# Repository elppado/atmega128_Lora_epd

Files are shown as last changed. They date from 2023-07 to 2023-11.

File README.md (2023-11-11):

# Atmega128_Lora_epd  wire-less Chat
## [ LoRa와 ePaper를 사용한 AVR 기반 저전력 다용도 통신 단말 ]

### 🚀 프로젝트 소개
------
atmega128과 Lora 모듈, 전자잉크 디스플레이를 사용하여 무선 채팅기 개발



### 🕰️ 개발 기간
------
* 22.07 ~ 22.09

### 📋 개발내용
------
- [Schematic](https://github.com/elppado/atmega128_Lora_epd/tree/main/PCB)
- [F/W](https://github.com/elppado/atmega128_Lora_epd/tree/main/firmware)  

### ⚙️ 개발환경
-----
* C
* **Tool** : xcode(avrdude_cross compile), kicad, fusion360

### 📋 BOM
------
Lora : NMT-UD434R0

Display : 2.13 inch EInk e-paper Display 250*122

Keypad : Q10

This project is licensed under the terms of the MIT license.

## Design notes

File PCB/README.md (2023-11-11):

# PCB
-------

- atmega128a
- LoRa Module
- e-ink display

### Schematic



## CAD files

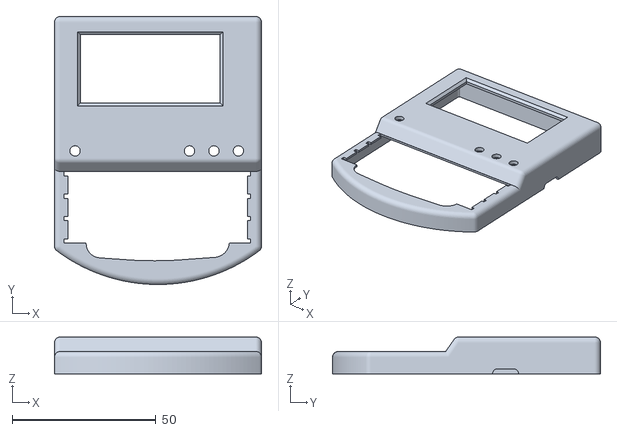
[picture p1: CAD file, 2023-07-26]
3D model/top.stl
72.0 x 93.2 x 12.9

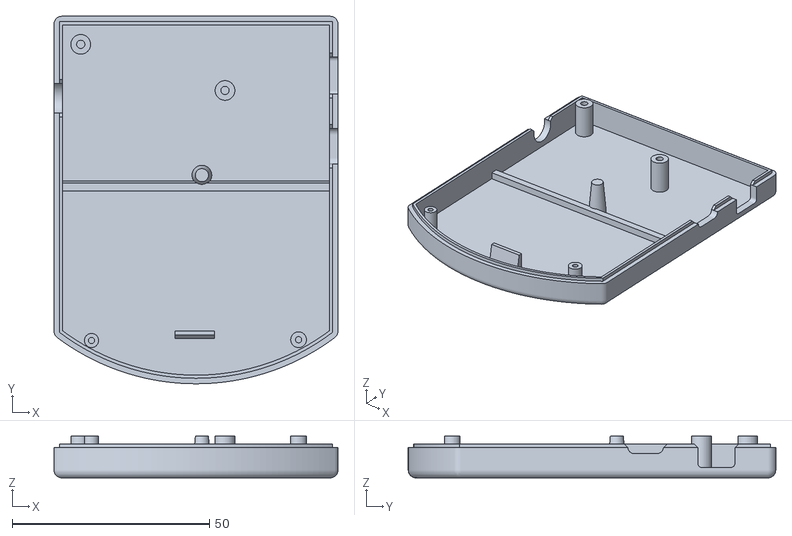
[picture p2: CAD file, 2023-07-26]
3D model/back.stl
72.0 x 93.2 x 10.6

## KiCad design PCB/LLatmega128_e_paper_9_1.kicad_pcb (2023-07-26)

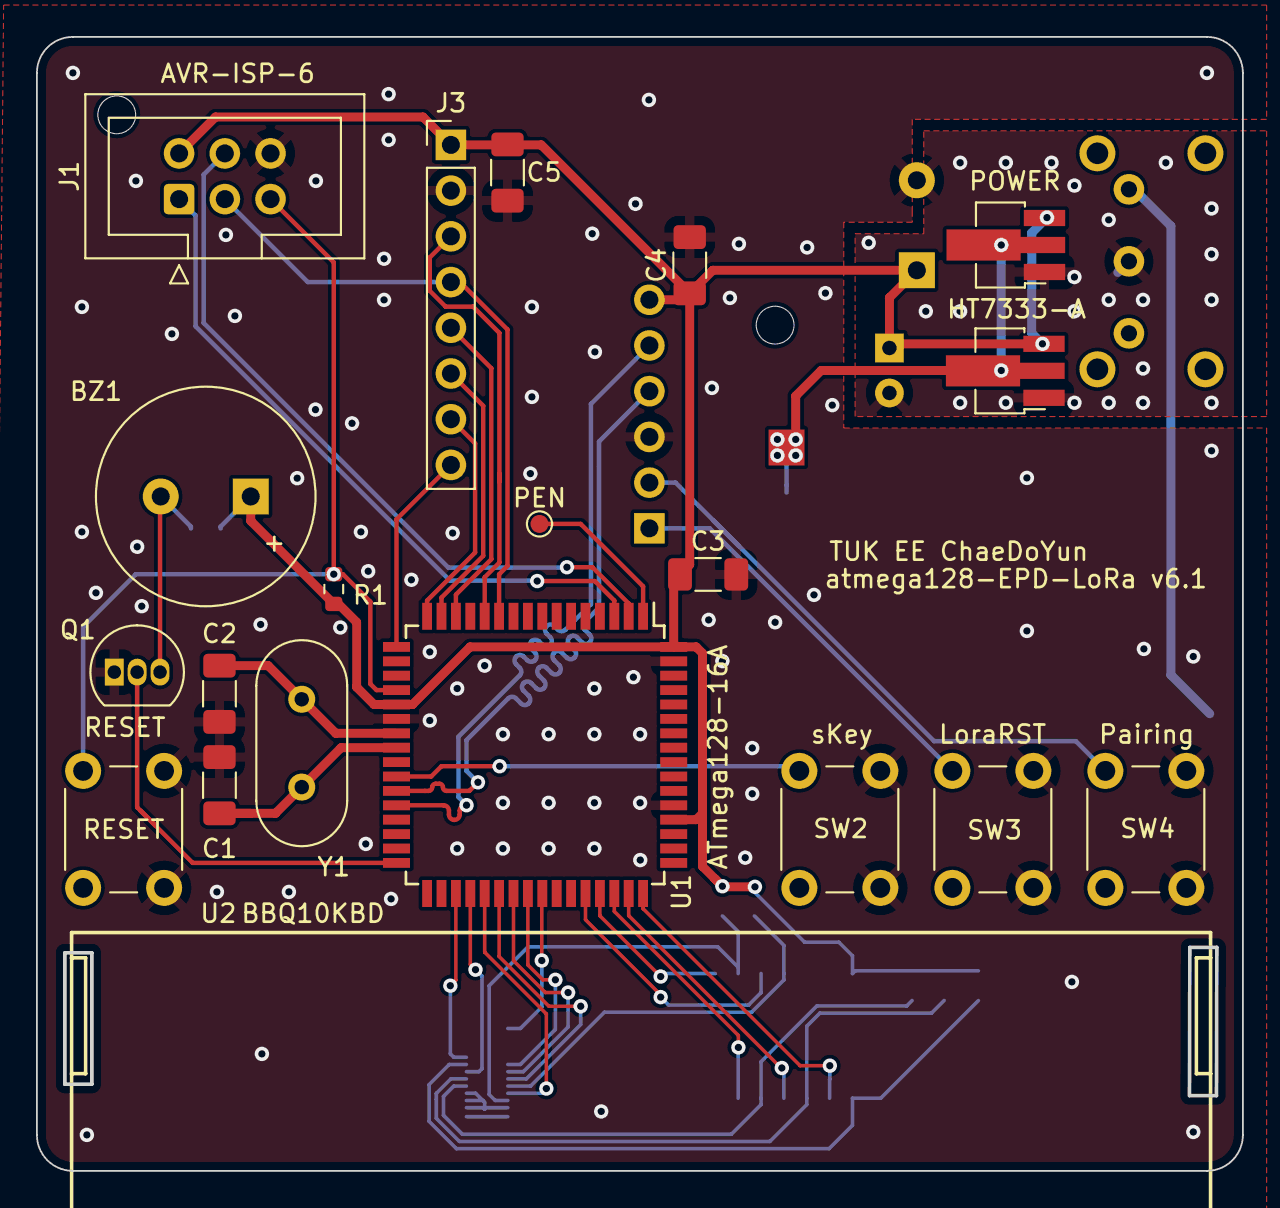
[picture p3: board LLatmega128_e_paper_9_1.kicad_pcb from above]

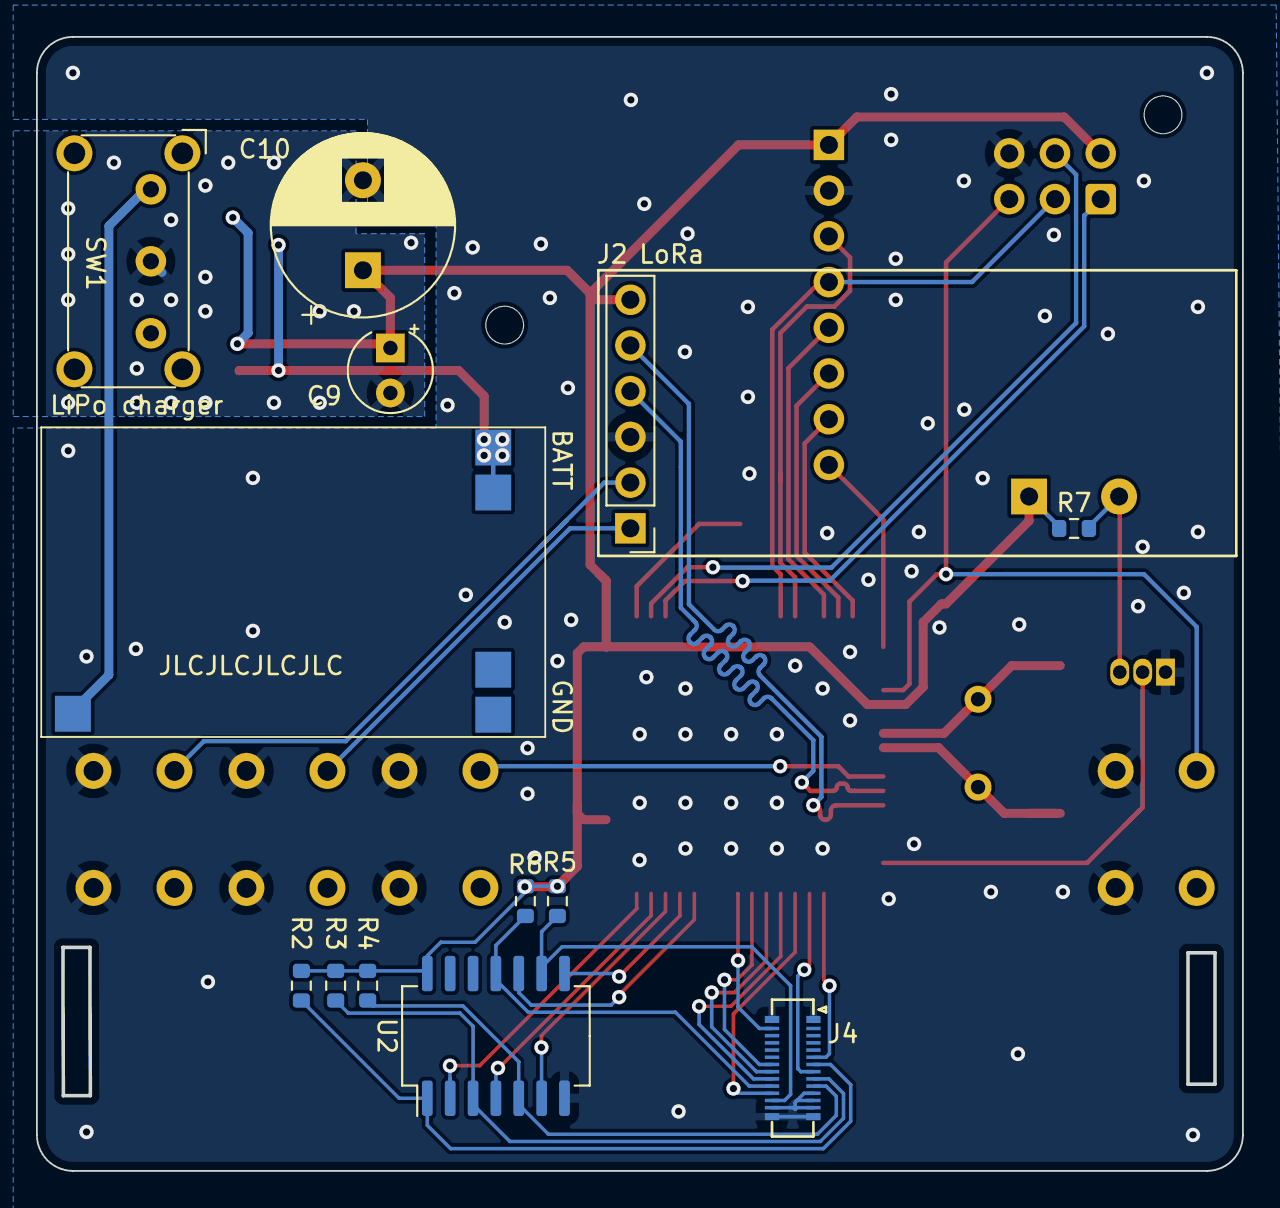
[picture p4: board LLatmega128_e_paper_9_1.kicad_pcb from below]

Board: 2 copper layers, 67.0 x 63.0 mm, 32 parts (12 on the bottom side), 38 nets.

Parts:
BZ1: Buzzer; Buzzer_12x9.5RM7.6
C1, C2: C22pF; C_1206_3216Metric_Pad1.33x1.80mm_HandSolder
C3, C4, C5: C_1206_3216Metric_Pad1.33x1.80mm_HandSolder
C9: CP_Radial_Tantal_D4.5mm_P2.50mm
C10: CP_Radial_D10.0mm_P5.00mm
J1: AVR-ISP-6; IDC-Header_2x03_P2.54mm_Vertical
J2: Conn_01x06_Male; PinHeader_1x06_P2.54mm_Vertical
J3: ePaper; PinHeader_1x08_P2.54mm_Vertical
J4: Conn_02x14_Counter_Clockwise; Hirose_BM14-24DS-2DSA_2x14_P2.00mm_Vertical
L1, L1#2: HT7333-A; SOT-89-3_Handsoldering
PEN: TestPoint_Pad_D1.0mm
POWER: SW_E-Switch_EG1224_SPDT_Angled
Q1: PN2222A; TO-92_Inline
R1: R10k; R_0603_1608Metric
R2, R3, R4, R5, R6, R7: R; R_0603_1608Metric
SW1, SW2, SW3, SW4: SW_Push; SW_PUSH_6mm_H4.3mm
U1: ATmega128-16A; TQFP-64_14x14mm_P0.8mm
U2: BBQ10KBD; Reverb_BTDR-1A
U2#2: 74HC14; SO-14_5.3x10.2mm_P1.27mm
Y1: Crystal; Crystal_HC49-4H_Vertical

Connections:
+3V3: BZ1.1 (-), C3.1, C4.1, C5.1, C9.1, C10.1, J1.2 (VCC), J2.6, J3.1, L1.3 (VOUT), L1#2.3 (VOUT), R1.1, R2.1, R3.1, R4.1, R5.1, R6.1, R7.1, U1.21 (VCC), U1.52 (VCC), U1.64 (AVCC), U2#2.14 (VCC)
-BATT: L1.2 (VIN), L1#2.2 (VIN)
/BUSY: J3.8, U1.17 (PB7)
/BUZZ: Q1.2 (B), U1.32 (PD7)
/COL1: U1.48 (PA3), U2#2.2
/COL2: U1.47 (PA4), U2#2.4
/COL3: U1.46 (PA5), U2#2.6
/COL4: U1.45 (PA6), U2#2.8
/COL5: U1.44 (PA7), U2#2.10
/CS: J3.5, U1.14 (PB4)
/D/C: J3.6, U1.15 (PB5)
/KCOL1: J4.7, R2.2, U2#2.1
/KCOL2: J4.9, R3.2, U2#2.3
/KCOL3: J4.10, R4.2, U2#2.5
/KCOL4: J4.17, R5.2, U2#2.9
/KCOL5: J4.19, R6.2, U2#2.11
/LoraRST: J2.1, SW3.2
/PIO6: J2.2, SW4.2
/RES: J3.7, U1.16 (PB6)
/ROW1: J4.6, U1.35 (PC0)
/ROW2: J4.8, U1.36 (PC1)
/ROW3: J4.18, U1.37 (PC2)
/ROW4: J4.20, U1.38 (PC3)
/ROW5: J4.21, U1.39 (PC4)
/ROW6: J4.22, U1.40 (PC5)
/ROW7: J4.27, U1.41 (PC6)
/RST: J1.5 (~RST), R1.2, SW1.2, U1.20 (~RESET)
/RXD0: J1.4 (MOSI), U1.2 (PE0)
/RXD1: J2.4, U1.27 (PD2)
/SCK: J1.3 (SCK), J3.4, U1.11 (PB1)
/SDI: J3.3, U1.12 (PB2)
/TXD0: J1.1 (MISO), U1.3 (PE1)
/TXD1: J2.5, U1.28 (PD3)
/X1: C1.2, U1.24 (XTAL1), Y1.2
/X2: C2.1, U1.23 (XTAL2), Y1.1
/sKEY: SW2.2, U1.26 (PD1)
GND: C1.1, C2.2, C3.2, C4.2, C5.2, C9.2, C10.2, J1.6 (GND), J2.3, J3.2, J4.1, J4.4, J4.5, J4.11, J4.12, J4.13, J4.14, J4.15, J4.16, J4.28, L1.1 (GND), L1#2.1 (GND), POWER.2, Q1.1 (E), SW1.1, SW2.1, SW3.1, SW4.1, U1.22 (GND), U1.53 (GND), U1.63 (GND), U2#2.7 (GND)
unnamed: BZ1.2 (+), Q1.3 (C), R7.2

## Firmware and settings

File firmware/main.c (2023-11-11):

/*
 * ATMEGAEPDLORA v1.c
 *
 * Created: 2022-07-17 오후 1:12:52
 * Author : chaedoyun
 */


//#define dev_colour_BLACK
#define dev_colour_WHITE


#include <avr/io.h>
#include <util/delay.h>
#include <avr/interrupt.h>
#include <avr/pgmspace.h>

#include "epd.h"
#include "buzz.h"
#include "keyscan.h"
#include "GPS.h"
//#include "uart.h"

#ifdef dev_colour_WHITE
    #include "font_W.h"

#else
    #include "font_B.h"
#endif


#define MAX_LEN 23



unsigned char TX_str[MAX_LEN];
unsigned char RX_str[MAX_LEN];
const unsigned char erase_str[MAX_LEN] = " ";

const unsigned char GPS_comm[] = "$gps";
const unsigned char GPS_dis_comm[]= "$dis";
const unsigned char Time_comm[] = "$time";


unsigned char str_po = 0;
unsigned char RX_po = 0;

unsigned char flag = 0;
unsigned char rx_flag = 1;




void str_to_epd(const unsigned char *str,unsigned char x, unsigned char y){ //str을 화면에 출력
    
    for (unsigned char i = 0; *(str+i) != '\0'; i++) {
        EPD_HW_Init(); // deepsleep 이후에 HW reset으로 꺠우기
        EPD_Dis_Part(x,y+(i*9),epd_font[(*(str+i)-32)],8,16);
        EPD_DeepSleep();
    }
}


void rx_str_sum(unsigned char *str, const unsigned char val){   //rx data 저장
    for (int i = 0; i < MAX_LEN; i++){
        if (*(str+i) == '\0'){
            *(str+i) = val;
            *(str+i+1) = '\0';
            
            return;
        }
    }
}

void str_sum(unsigned char *str, const unsigned char val){  // 키보드 입력 문자 덧셈
    *(str+flag) = val;
    *(str+flag+1) = '\0';
    flag++;
}


void init_UART1(unsigned char baud){    // uart1 init
    UBRR1H = (unsigned char)(baud >> 8);
    UBRR1L = (unsigned char)baud;
    
    UCSR1A &= ~(1 << U2X1);
    UCSR1B |= (1 << TXEN1) | (1 << RXEN1) | ( 1 << RXCIE1);
    UCSR1B &= ~(1 << UCSZ12);
    UCSR1C &= ~( 1 << UMSEL1) & ~( 1 << UPM11) & ~( 1 << UPM10) & ~( 1 << USBS1);
    UCSR1C |= (1<<UCSZ11) | (1 << UCSZ10);
}


void word_UART1(const unsigned char data){  // uart rx word 가져오기
    while( !(UCSR1A & (1<<UDRE1)));
    UDR1 = data;
}


void str_UART1(const unsigned char *str){   // uart rx str 가져오기
    while (*str != '\0') {
        word_UART1(*str);
        str++;
    }
    word_UART1(CR);
    word_UART1(LF);
}



void comm_find(void){
    switch (RX_str[0]) {
        case DC1:   // case GPS
            GPS_return();
            break;
            
        case DC2:   // case Lati
            for (unsigned char i = 0; RX_str[i] != 0; i++)
                you_GPS_lati[i] = RX_str[i+1];
            GPS_return_logi_flag = 0;
            break;
            
        case DC3:   // case logi
            for (unsigned char i = 0; RX_str[i] != 0; i++)
                you_GPS_logi[i] = RX_str[i+1];
            GPS_return_lati_flag = 0;
            break;
            
        default:    // 일반 메세지 처리
            SSound(Do);
            SSound(Re);
            str_to_epd(RX_str,RX_x,RX_y);
            break;
    }
    for (unsigned char i = 0; i < MAX_LEN; i++)
        RX_str[i] = '\0';
}



/* 수신 > 문자열 저장
 문자열 시작이 DC1|DC2|DC3 > GPS처리
 아니면 일반문자열로 처리 (화면 출력)
 */


ISR(USART1_RX_vect){ //  UART RX 인터럽트
    unsigned char ch = UDR1;
    if ((ch != CR) && (ch != LF)) {
        rx_str_sum(RX_str,ch);
    }
    else if (ch == LF){
        comm_find();
    }
}


void init_port(){
    DDRA = 0xff;
    DDRD |= (1 << PD7);
    DDRD &= ~(1 << PD1);
    PORTD |= (1 << PD1);
    DDRB = 0x7f;
    DDRC = 0x00;
}


void init_BOOT(){
    interrupt_init();
    init_port();
    PORTC = 0xff;
    init_UART1(47); // baud rate 47, 9600bps, fosc = 7.3728 MHz
    init_UART0(47);
    
    SSound(Do);
    
    EPD_HW_Init();
    EPD_SetRAMValue_BaseMap(gImage_1);
    EPD_DeepSleep();

    SSound(Mi);
    SSound(Sol);
    // 부팅 완료;
}


int main(void){
    unsigned char kval = '\0';
    
    init_BOOT();
    
    while (1) {
        if (keyScan()) {
            
            kval = kbdq10[alt_flag][keypad_in()];
            
            if (kval != '\0'){ // 리턴값이 \0 (사용하지 않는 키패드) 이면서
                EPD_HW_Init();
                
                switch (kval) {
                    case CR:
                        if (TX_str[0] == '$') {    // 특수 호출 메세지 시작값
                            
                            if ((TX_str[1] == GPS_comm[1]) && (TX_str[2] == GPS_comm[2]) && (TX_str[3] == GPS_comm[3]))  {
                                EPD_SetRAMValue_BaseMap(gImage_1);
                                EPD_DeepSleep();
                                GPS();
                            }
                            else if ((TX_str[1] == GPS_dis_comm[1]) && (TX_str[2] == GPS_dis_comm[2]) && (TX_str[3] == GPS_dis_comm[3])){
                                EPD_SetRAMValue_BaseMap(gImage_1);
                                EPD_DeepSleep();
                                GPS_dis();
                            }
                            else if ((TX_str[1] == Time_comm[1]) && (TX_str[2] == Time_comm[2]) && (TX_str[3] == Time_comm[3]) && (TX_str[4] == Time_comm[4])){
                                EPD_SetRAMValue_BaseMap(gImage_1);
                                EPD_DeepSleep();
                                get_time();
                            }
                        }
                        
                        else{
                            //word_UART1(DC4);
                            str_UART1(TX_str); //UART 송신
                            SSound(Re);//송신 완료 알림
                            SSound(Do);
                            
                            _delay_ms(3000);
                            EPD_SetRAMValue_BaseMap(gImage_1);
                            EPD_DeepSleep();
                        }
                        
                        for (unsigned char i = 0; i < MAX_LEN; i++){
                            TX_str[i] = '\0'; // TX, 디스플레이 후 문자열 버퍼 초기화
                        }
                        str_po = 0;
                        flag = 0;
                        break;
                    
                    case BS:
                        str_po--; //커서--
                        
                        if (str_po < 0)
                            str_po = 0;
                        
                        flag--; //문자열 합치기--
                        
                        if (flag < 0)
                            flag = 0;
                        
                        EPD_HW_Init();
                        EPD_Dis_Part(TX_x,TX_y+(str_po*9),epd_font[0],8,16);
                        EPD_DeepSleep();
                        break;
                        
                    case SPB:
                        str_sum(TX_str,kval); // 문자열 뒤에 추가.
                        str_po++;// 커서 위치
                        break;
                        
                    default:
                        str_sum(TX_str,kval); // 문자열 뒤에 추가.
                        EPD_Dis_Part(TX_x,TX_y+(str_po*9),epd_font[(kval-32)],8,16); // 키보드 입력한 한글자만 화면 출력
                        //word_UART1(kval);
                        EPD_DeepSleep();
                        str_po++; // 커서 위치
                        break;
                }
            }
        }
    }
}

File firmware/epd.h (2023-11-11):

/*
 * epd.h
 *
 * Created: 2022-07-17 오후 1:14:07
 *  Author: chaedoyun
 */ 


#ifndef EPD_H_
#define EPD_H_


#define SCK_Pin PB1
#define SDI_Pin PB2
#define CS_Pin PB4
#define DC_Pin PB5
#define RES_Pin PB6
#define BUSY PB7


#define EPD_W21_MOSI_0	PORTB &= ~( 1<< SDI_Pin)
#define EPD_W21_MOSI_1	PORTB |= ( 1<< SDI_Pin)

#define EPD_W21_CLK_0	PORTB &= ~( 1<< SCK_Pin)
#define EPD_W21_CLK_1	PORTB |= ( 1<< SCK_Pin)

#define EPD_W21_CS_0	PORTB &= ~( 1<< CS_Pin)
#define EPD_W21_CS_1	PORTB |= ( 1<< CS_Pin)

#define EPD_W21_DC_0	PORTB &= ~( 1<< DC_Pin)
#define EPD_W21_DC_1	PORTB |= ( 1<< DC_Pin)

#define EPD_W21_RST_0	PORTB &= ~( 1<< RES_Pin)
#define EPD_W21_RST_1	PORTB |= ( 1<< RES_Pin)


//250*122///////////////////////////////////////


#define MAX_LINE_BYTES 16// =128/8
#define MAX_COLUMN_BYTES  250

#define ALLSCREEN_GRAGHBYTES  4000





////////FUNCTION//////
void driver_delay_us(unsigned int xus);
void driver_delay(unsigned long xms);
void SPI_Delay(unsigned char xrate);


//EPD
void Epaper_READBUSY(void);
void SPI_Write(unsigned char value);
void Epaper_Write_Command(unsigned char cmd);
void Epaper_Write_Data(unsigned char datas);

void EPD_HW_Init(void); //Electronic paper initialization
void EPD_Part_Init(void); //Local refresh initialization

void EPD_Part_Update(void);
void EPD_Update(void);

void EPD_WhiteScreen_Black(void);
void EPD_WhiteScreen_White(void);
void EPD_DeepSleep(void);
//Display
void EPD_WhiteScreen_ALL(const unsigned char * datas);
void EPD_SetRAMValue_BaseMap(const unsigned char * datas);
void EPD_Dis_Part(unsigned int x_start,unsigned int y_start,const unsigned char * datas,unsigned int PART_COLUMN,unsigned int PART_LINE);





void driver_delay_us(unsigned int xus)  //1us
{
	for(;xus>1;xus--);
}//us delay


void driver_delay(unsigned long xms) //1ms
{
	unsigned long i = 0 , j=0;

	for(j=0;j<xms;j++)
	{
		for(i=0; i<256; i++);
	}
}



void EPD_WhiteScreen_ALL(const unsigned char * datas)
{
   unsigned int i;
    Epaper_Write_Command(0x24);   //write RAM for black(0)/white (1)
   for(i=0;i<ALLSCREEN_GRAGHBYTES;i++)
   {
     Epaper_Write_Data(pgm_read_byte(&datas[i]));
   }
   EPD_Update();
}




//////////////////////SPI///////////////////////////////////
void SPI_Delay(unsigned char xrate)
{
	unsigned char i;
	while(xrate)
	{
		for(i=0;i<2;i++);
		xrate--;
		
	}
}


void SPI_Write(unsigned char value)
{
	unsigned char i;
	SPI_Delay(1);
	for(i=0; i<8; i++)
	{
		EPD_W21_CLK_0;
		SPI_Delay(1);
		if(value & 0x80)
		EPD_W21_MOSI_1;
		else
		EPD_W21_MOSI_0;
		value = (value << 1);
		SPI_Delay(1);
		driver_delay_us(1);
		EPD_W21_CLK_1;
		SPI_Delay(1);
	}
}


void Epaper_Write_Command(unsigned char cmd)
{
	SPI_Delay(1);
	EPD_W21_CS_0;
	EPD_W21_DC_0;   // command write
	SPI_Write(cmd);
	EPD_W21_CS_1;
}
void Epaper_Write_Data(unsigned char datas)
{
	SPI_Delay(1);
	EPD_W21_CS_0;
	EPD_W21_DC_1;   // data write
	SPI_Write(datas);
	EPD_W21_CS_1;
}

/////////////////EPD settings Functions/////////////////////
//////////////////////////////////////////////////////////////////////////////////////////////////
//SSD1680
void EPD_HW_Init(void){
    
    EPD_W21_RST_0;  // Module reset
    _delay_ms(10); //At least 10ms delay
    EPD_W21_RST_1;
    _delay_ms(10); //At least 10ms delay

    Epaper_READBUSY();
    Epaper_Write_Command(0x12);  //SWRESET
    Epaper_READBUSY();
       
     Epaper_Write_Command(0x01); //Driver output control
     Epaper_Write_Data(0xF9);
     Epaper_Write_Data(0x00);
     Epaper_Write_Data(0x00);

     Epaper_Write_Command(0x11); //data entry mode
     Epaper_Write_Data(0x01);

     Epaper_Write_Command(0x44); //set Ram-X address start/end position
     Epaper_Write_Data(0x00);
     Epaper_Write_Data(0x0F);    //0x0F-->(15+1)*8=128

     Epaper_Write_Command(0x45); //set Ram-Y address start/end position
     Epaper_Write_Data(0xF9);   //0xF9-->(249+1)=250
     Epaper_Write_Data(0x00);
     Epaper_Write_Data(0x00);
     Epaper_Write_Data(0x00);

     Epaper_Write_Command(0x3C); //BorderWavefrom
     Epaper_Write_Data(0x05);
         
     Epaper_Write_Command(0x21); //  Display update control
     Epaper_Write_Data(0x00);
     Epaper_Write_Data(0x80);
         
     Epaper_Write_Command(0x18); //Read built-in temperature sensor
     Epaper_Write_Data(0x80);

     Epaper_Write_Command(0x4E);   // set RAM x address count to 0;
     Epaper_Write_Data(0x00);
     Epaper_Write_Command(0x4F);   // set RAM y address count to 0X199;
     Epaper_Write_Data(0xF9);
     Epaper_Write_Data(0x00);
     Epaper_READBUSY();
}

/*
//////////////////////////////All screen update////////////////////////////////////////////
void EPD_WhiteScreen_ALL(const unsigned char * datas)
{
	unsigned int i;
	Epaper_Write_Command(0x24);   //write RAM for black(0)/white (1)
	for(i=0;i<ALLSCREEN_GRAGHBYTES;i++)
	{
		Epaper_Write_Data(pgm_read_byte(&datas[i]));
	}
	EPD_Update();
}
*/
/////////////////////////////////////////////////////////////////////////////////////////

void EPD_Update(void)
{
	Epaper_Write_Command(0x22); //Display Update Control
	Epaper_Write_Data(0xF7);
	Epaper_Write_Command(0x20); //Activate Display Update Sequence
	Epaper_READBUSY();

}
void EPD_Part_Update(void)
{
	Epaper_Write_Command(0x22); //Display Update Control
	Epaper_Write_Data(0xFF);
	Epaper_Write_Command(0x20); //Activate Display Update Sequence
	Epaper_READBUSY();
}
void EPD_DeepSleep(void)
{
	Epaper_Write_Command(0x10); //enter deep sleep
	Epaper_Write_Data(0x01);
    //Epaper_READBUSY();
    _delay_ms(100);
}
void Epaper_READBUSY(void)
{
    while(PINB & 0x80);

}
///////////////////////////Part update//////////////////////////////////////////////
void EPD_SetRAMValue_BaseMap( const unsigned char * datas)
{
	unsigned int i;
	const unsigned char  *datas_flag;
	datas_flag=datas;

	Epaper_Write_Command(0x24);   //Write Black and White image to RAM

	for(i=0;i<ALLSCREEN_GRAGHBYTES;i++){
        
		Epaper_Write_Data(pgm_read_byte(&datas[i]));
	}

	datas=datas_flag;

	Epaper_Write_Command(0x26);   //Write Black and White image to RAM

	for(i=0;i<ALLSCREEN_GRAGHBYTES;i++)
	{
		Epaper_Write_Data(pgm_read_byte(&datas[i]));
	}

	EPD_Update();
}
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

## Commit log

2022-09-26 emmb 제출 테스트 중...
2023-07-26 edit & update
    [LLatmega128_e_paper_9_1.kicad_pcb, LLatmega128_e_paper_9_1.kicad_sch, LLatmega128_e_paper_9_1_emver.kicad_pcb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]
2023-11-11 .gitignore 생성
